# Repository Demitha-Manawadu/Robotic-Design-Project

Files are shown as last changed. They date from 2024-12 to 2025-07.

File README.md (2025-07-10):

# Robotic Design Project - EN2533

## project overview 

# My Project

This is  the Demo Video of the project - [here]( https://www.linkedin.com/posts/demitha-manawadu-9750452a4_robotics-engineering-innovation-activity-7279574753667858432-JbwE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).

This project is focused on designing and building a robot capable of performing various tasks in an autonomous environment. The robot is equipped with sensors and actuators to handle tasks such as bar counting, line navigation, maze navigation, box manipulation, and more. This robot is designed for use in the EN2533 - Robot Design and Competition module and follows a modular design approach to handle different tasks sequentially.

WhatsApp Image 2024-12-21 at 21 46 30_15445ea4               
WhatsApp Image 2024-12-21 at 21 46 29_c666b268

## Features

- 🚗 **Line Navigation:** Navigate predefined paths using IR sensor arrays and color sensors.
- 🔢 **Bar Counting:** Detect and count horizontal bars placed along a predefined path.
- 🧭 **Maze Navigation:** Grab a virtual box and navigate through a maze to place it in the target location.
- 🤖 **Box Arrangement:** Arrange a set of boxes in ascending or descending order of height using a custom SolidWorks-designed mechanical robot arm powered by servo motors. A Sharp IR sensor integrated into the robotic gripper allows for height differentiation.
- 🌈 **Color Line Following:** Follow a colored line on the ground using color sensors.
- 📏 **Dashed Line Following:** Follow a dashed line using the IR sensors.
- 🚪 **Portal Navigation:** Detect and navigate through portals or gateways.
- 🕵️‍♂️ **Hidden Task and Chamber Insertion:** Solve a hidden task and insert a box inside a chamber.
- 🪙 **Coin Drop:** Drop a coin into a specific target area.

## Design Overview

### Hardware requirements:
Sensors

The robot employs various sensors for accurate detection and navigation, including:

- **Ultrasonic Sensors:** Employed for detecting walls and chambers.
- **Sharp IR Sensor:** Mounted on top for measuring distance, especially during portal navigation and for box height differentiation.
- **TCS34725 Color Sensor:** Used for color detection in line following tasks.
- **REKHA TCRT5000 Reflectance Sensor Array:** For precise line tracking.

 **Actuators**
- Robotic arm and gripper: Gripper mechanism and slider operations for lifting boxes are performed using two MG90S servo motors.

**JGA25-370 DC motor**
- integrated to the wheels of the robot.

 **Microcontrollers**
- Arduino Mega 2560- The microcontroller that controls all the functionalities of the robot

### Mechanical Design

The mechanical design of the robot was fully customized using SolidWorks, encompassing both the chassis and the robotic arm. The robotic arm, equipped with a gripper, utilizes a rack-and-pinion mechanism for precise linear movement, enabling efficient box grabbing, lifting, and dropping operations.

The chassis features a two-layer acrylic board structure, mounted with spacers for stability. This compact design was carefully crafted to optimize space and ensure the robot can effectively carry out its tasks.
WhatsApp Image 2024-12-29 at 15 23 47_e17c57a6

WhatsApp Image 2024-12-29 at 15 19 25_0207914a

WhatsApp Image 2024-12-29 at 15 19 25_487d0368

## Algorithms

The robot’s navigation algorithms rely on real-time data from the sensors. Each task follows a defined sequence, enabling the robot to adapt its actions based on sensor inputs. The algorithms include:

## Task-2024
The full Task Documentation can be found in:
[Task 2024 v1.1](https://online.uom.lk/mod/resource/view.php?id=432368)



### task 01
### Counting and Line Navigation
The robot will travel along a straight path at a steady pace, guided by encoder feedback. As it encounters a barcode, it will measure the duration that the central IR sensor is exposed to white segments. This duration will be compared to a predetermined threshold, and if it exceeds the threshold, the value 1 will be recorded; otherwise, 0 will be stored. The robot will continue this detection process until three consecutive 0s are detected, indicating the end of the barcode.



### task 02
### Virtual Box Movement
If the Output is 0: The robot approaches the virtual box, grabs it, and moves forward to place it at a specific location. 

The robot identifies which of the two squares (blue or red) is free from gate, grabs the box, and navigates through the maze, ensuring it places the box at the appropriate location.

Movements are carefully controlled accoriding to the given constraints. The optimal path will be hardcoded and the encoders and sensor array with PD will be used for correct navigation.



### task 03
### Color line following
We use the TCS34725 color sensor alongside the REKHA TCRT5000 reflectance sensor array for accurate tracking. 

First, we calibrate the REKHA array to differentiate between the line and the background. The TCS34725 is calibrated to detect the hue of the colored line and this value will be stored for the future use in task 6.

The REKHA array keeps the robot centered on the path, while the TCS34725 verifies it's following the correct color.



### task 04
### Dotted Line Navigation
The robot follows a white dashed line using an 8-IR sensor array, dynamically adjusting its speed based on sensor input.

It maintains a forward stare when detecting black, and upon detecting the white line, it follows the path accordingly.

The robot stops when all sensors detect the white line simultaneously, signaling the end of the dashed line segment



### task 05
### Portal Navigation
For portal navigation, the ToF sensor is mounted on top of the robot (which we are going to use for height mesuring), continuously reading the distance to the gate. 

As the gate is opening and the distance starts to decrease, the robot uses this data to determine when to move forward. 
The frequent readings from the ToF sensor allow the system to  passes through the gate without collision. 
And for more accuracy we will use the ultrasonic sensor reading which is mounted in front of the robot as an additional data whether there is no obstacle in front of it.



### task 06
### Box Arrangement
When robot moves near to boxes it measures the height of each box using sharp IR sensor which is attached to the up down mechanism of the robot arm. It can differenciate the heights of 5,10,15 boxes.

Then accoring to the paths we define robot will grab the each box and place them according to the ascending or descending order depending on the colour it detected.



### task 07
### Hidden Task and Chamber Insertion
The line following robot will navigate along a the path and grab the box at stage 7 using the gripper, an ultra sonic sensor will detect the chamber and the robot will stop precisely right infront of it, release the box, will close the gripper and push the box inside the chamber using the closed gripper.



### task 08
### Coin Drop and Task Completion
The robot will move in the uneven terrain and detect walls using an ultra sonic sensor and move while avoiding the walls, until a black cross is detected to the IR sensor array.

once a cross is detected the robot will and the coin will be released on the cross using a sliding mechanism thats inbuilt in to the chassis of the robot



## Task Allocation
Provide an overview of the tasks allocated to different team members.

- **Team Member 1**: [Eshan S.G.S 220148G]
  - Tasks: [Task 2,Coding for Line following ,Implement the alogorithm for maze solving,Task 8,Testing robot behavior,coding for task 3,and 4]

- **Team Member 2**: [Manawadu M.D-220381M]
  - Tasks: [task 6,task 7,Desinging the robot arm and chasis,implement the alogorithm for box arrangement,mounting the robot mechanism]

- **Team Member 3**: [Wickramasinghe S.D-220701X]
  - Tasks: [task 1,Power circuit designing and soldering,Assembling the robot ,Testing the robot behavior, coin drop mechanism designing and implementing]
  - 
- **Team Member 4**: [Gunasekara V.G.V-220193M]
  - Tasks: [Solidworks drawing for robot arm and chisis,Coding for task 6 and 7,assembling the robot arm]
 
- **Team Member 5**: [Ravishan B.B.N-220533H]
   - Tasks: [task 5,circuit designing and robot assembling,Testing the robot behavior]

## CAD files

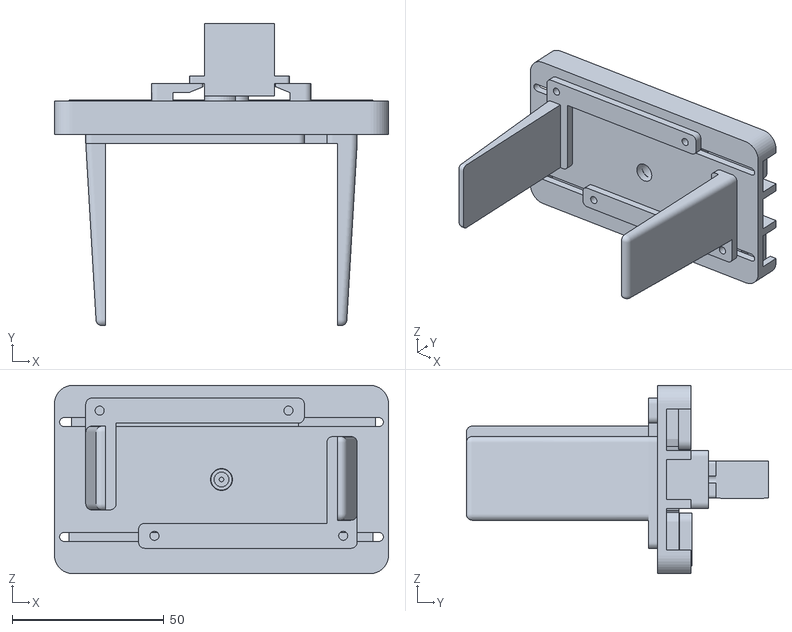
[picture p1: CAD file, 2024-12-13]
solidworks files/gripper/assembly of gripper.STL
110.0 x 99.6 x 62.0

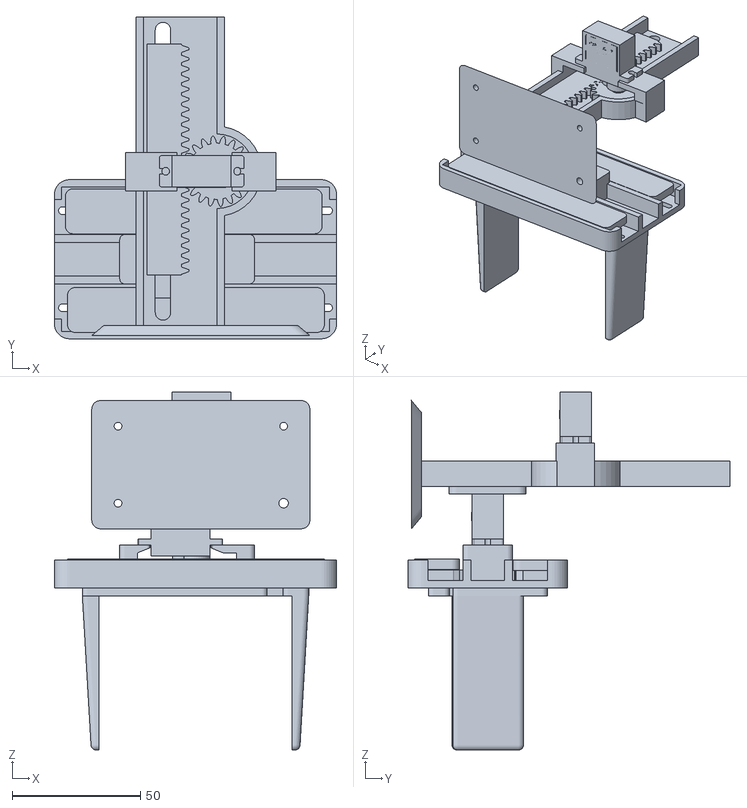
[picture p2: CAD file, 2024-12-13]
solidworks files/assembly/arm assem.STL
110.0 x 125.3 x 139.4

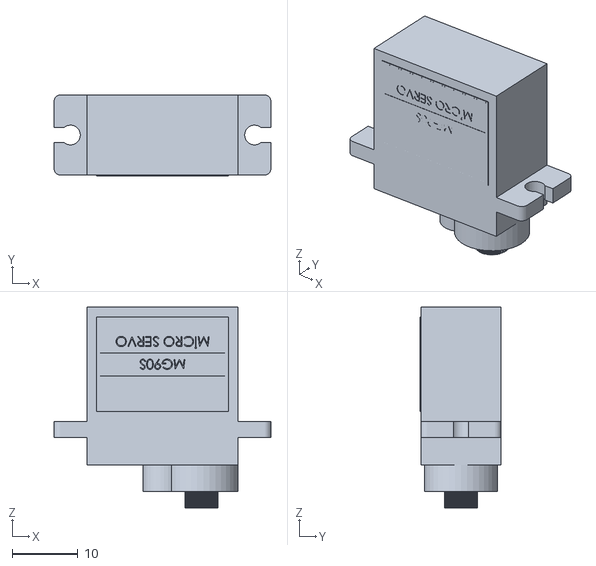
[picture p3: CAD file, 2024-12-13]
solidworks files/casing/arm assem - MG90-servo-1.STL
33.0 x 12.3 x 30.5

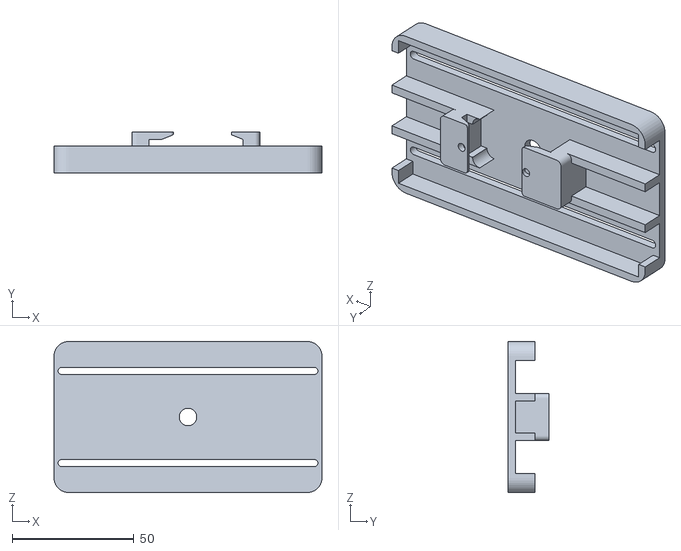
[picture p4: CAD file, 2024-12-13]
solidworks files/gripper/gripper assem - casing-1.STL
110.0 x 16.8 x 62.0

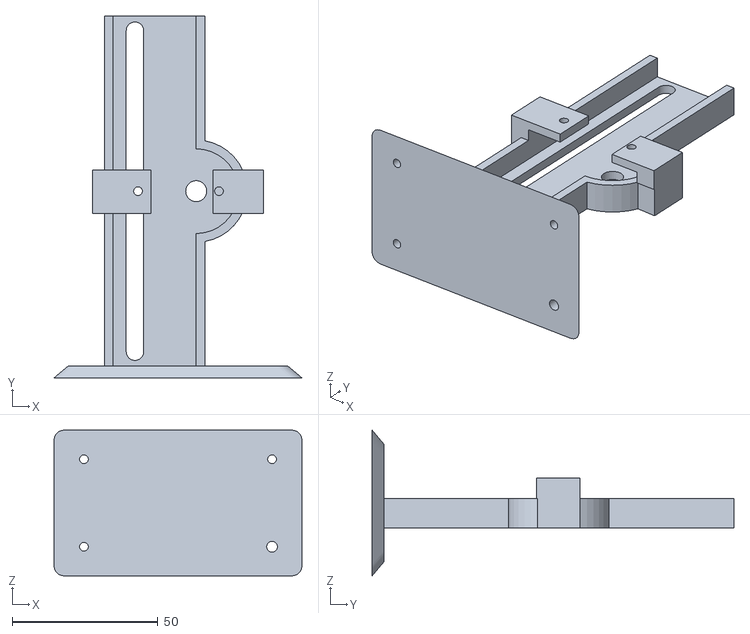
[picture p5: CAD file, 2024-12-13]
solidworks files/casing/arm assem - casing_new_arm-1.STL
85.0 x 124.0 x 50.0

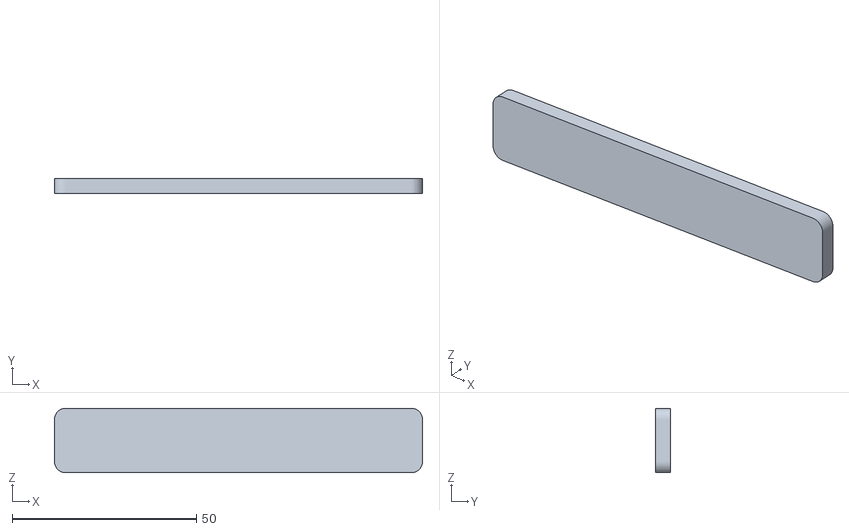
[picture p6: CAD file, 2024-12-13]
solidworks files/gripper/gripper assem - plate_gripper-1.STL
100.0 x 4.00 x 17.5

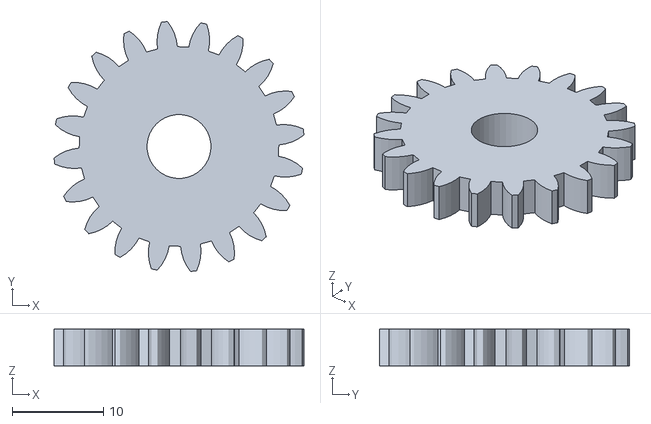
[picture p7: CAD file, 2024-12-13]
solidworks files/casing/arm assem - spur gear_am-1.STL
27.4 x 27.4 x 4.00

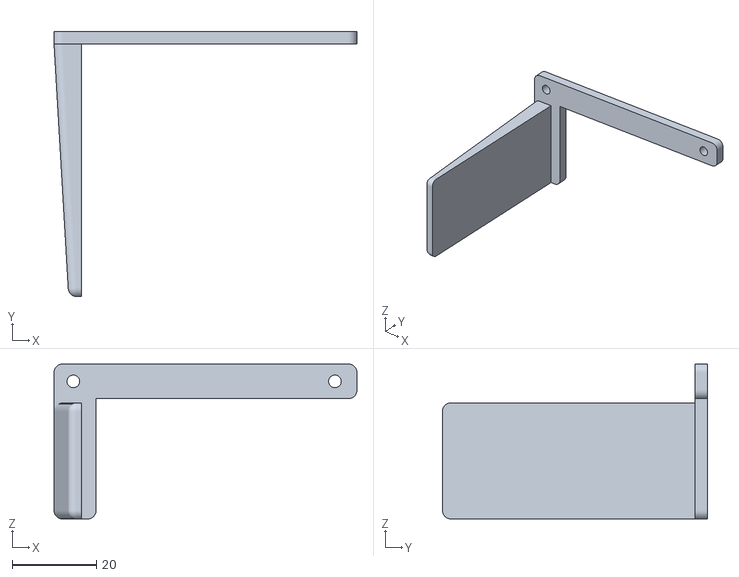
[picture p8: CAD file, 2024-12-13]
solidworks files/gripper/gripper assem - gripper jaw-1.STL
72.0 x 63.0 x 36.8

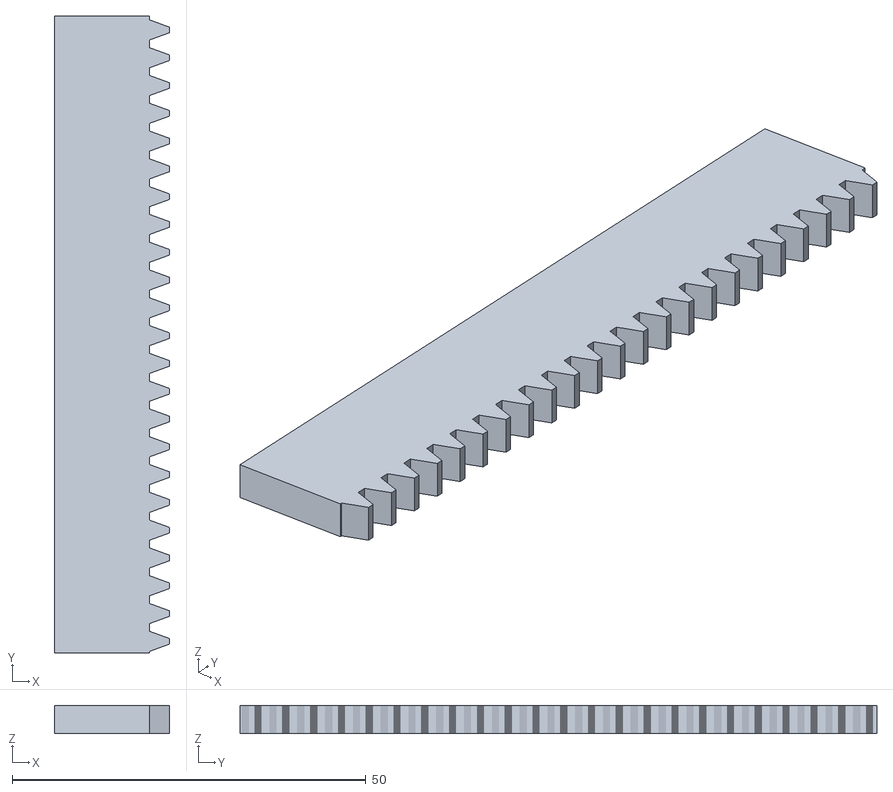
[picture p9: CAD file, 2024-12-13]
solidworks files/casing/arm assem - rack spur rectangular_am-1.STL
16.2 x 90.0 x 4.00

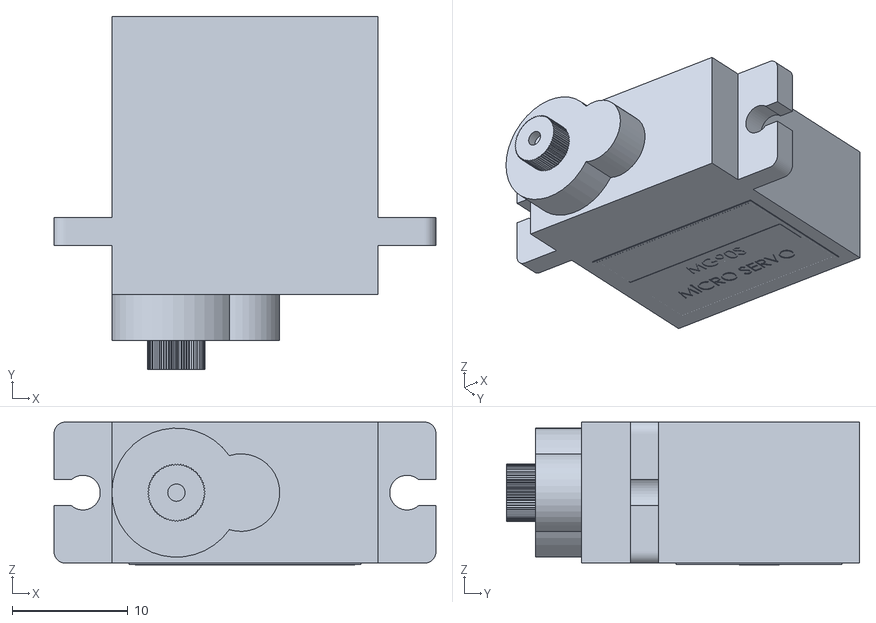
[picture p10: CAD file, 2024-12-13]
solidworks files/gripper/gripper assem - MG90-servo-1.STL
33.0 x 30.5 x 12.4

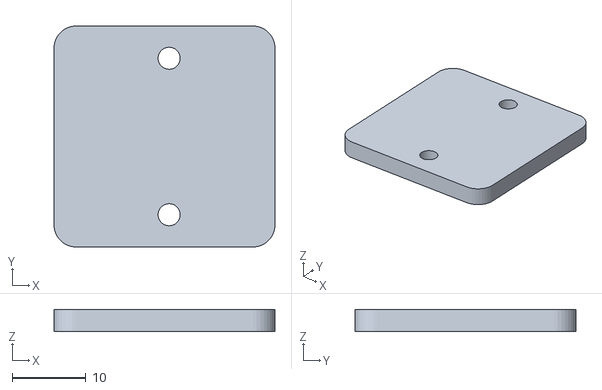
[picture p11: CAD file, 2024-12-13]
solidworks files/casing/arm assem - square-1.STL
30.0 x 30.0 x 3.00

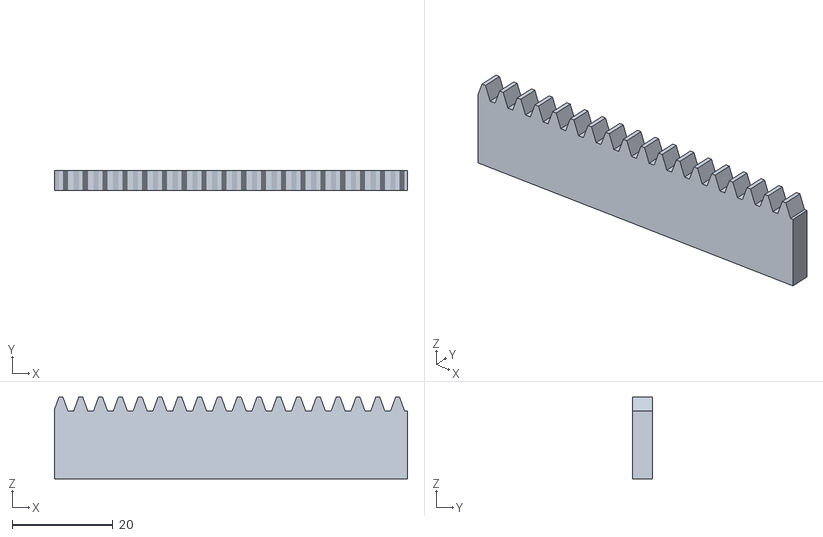
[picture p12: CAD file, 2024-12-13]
solidworks files/gripper/gripper assem - rack spur rectangular_am-4.STL
70.0 x 4.00 x 16.2

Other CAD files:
solidworks files/gripper/gripper assem - gripper jaw-2.STL
solidworks files/gripper/gripper assem - rack spur rectangular_am-7.STL
solidworks files/gripper/gripper assem - plate_gripper-2.STL
solidworks files/gripper/gripper assem - spur gear_am-2.STL

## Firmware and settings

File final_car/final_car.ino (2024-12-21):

#include <Arduino.h>
#include "PIDControl.h"
#include "SensorControl.h"
#include "MotorControl.h"
#include "Buzzer.h"
#include "ColorSensor.h"
#include "LineFollowAndTurn.h"
#include "task2.h"
#include "button.h"
#include "menu.h"
#include "OLED_Display.h"
#include "roboArm.h"
ButtonReader myBtnReader;
Buzzer buzzer;
//ColorSensor colorSensor;
OLEDDisplay oled; // single OLED object
#include "coindrop.h"
#include "Barcode.h"
void setup() {
  void setuplikesetup();
  setupsen() ;
  setupServo();
  Serial.begin(9600);
  myBtnReader.initPins();
  oled.init(); 
  initializeSensors();
  //calibrateSensors();
  setupEncoders();
  setupMotors();
  menu_init();
  digitalWrite(53,LOW);
  digitalWrite(51,LOW);
  digitalWrite(49,LOW);
  // put your setup code here, to run once:

}

void loop() {
    button_t btn = myBtnReader.readButton();
  if (btn != BTN_NONE) {
    menu_update(btn); // update menu logic
  }
  menu_draw(); // draw current menu state
  delay(10);
  // put your main code here, to run repeatedly:

}

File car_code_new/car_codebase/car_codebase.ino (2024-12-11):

#include "MotorControl.h"
#include "SensorControl.h"
#include "AdvancedMotorControl.h"
#include "MovementControl.h"
#include "OLED_Display.h"
#include "BarcodeDetection.h"
#include "Buzzer.h"
#include "ColorSensor.h"
#include "LineFollowAndTurn.h"
#include "task2.h"
#include "button.h"
#include "menu.h"

ButtonReader myBtnReader;
Buzzer buzzer;
ColorSensor colorSensor;
OLEDDisplay oled; // single OLED object

const int threshold = 500;
const int maxLines = 3;    
const int targetSpeed = 180;
BarcodeDetection barcodeDetector(threshold, maxLines, targetSpeed);

void setup() {
  Serial.begin(9600);
  myBtnReader.initPins();
  oled.init();  // initialize OLED
  setupMotors();
  buzzer.playBeep(); 
  setupSensors();
  buzzer.playBeep();    
  setupEncoders();

  menu_init(); // initialize menu
}

void loop() {
  button_t btn = myBtnReader.readButton();
  if (btn != BTN_NONE) {
    menu_update(btn); // update menu logic
  }
  menu_draw(); // draw current menu state
  delay(10);
}

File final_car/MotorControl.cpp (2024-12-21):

#include "MotorControl.h"
#include <Arduino.h>
#include "OLED_Display.h"
#include "PIDControl.h"

const int leftMotorForward = 48;
const int leftMotorBackward = 50;
const int rightMotorForward = 46;
const int rightMotorBackward = 44;

const int enaPin = 8;
const int enbPin = 9;

// Encoder pins
const int leftEncoderB = 18;
const int leftEncoderA = 19;
const int rightEncoderB = 3;
const int rightEncoderA = 2;

// Encoder counts
volatile long leftEncoderCount = 0;
volatile long rightEncoderCount = 0;

// // Constants to map degrees to encoder counts
// const float ENCODER_COUNTS_PER_DEGREE = 11.99;  // Adjust this value based on your setup

// PID control variables for turning
float turnKp = 1.0;  // Proportional gain for turning
float turnKi = 0.0;  // Integral gain for turning
float turnKd = 0.5;  // Derivative gain for turning
float turnLastError = 0;
float turnIntegral = 0;

void setupMotors() {
  pinMode(leftMotorForward, OUTPUT);
  pinMode(leftMotorBackward, OUTPUT);
  pinMode(rightMotorForward, OUTPUT);
  pinMode(rightMotorBackward, OUTPUT);
  pinMode(enaPin, OUTPUT);
  pinMode(enbPin, OUTPUT);
}

void setupEncoders() {
  pinMode(leftEncoderA, INPUT);
  pinMode(leftEncoderB, INPUT);
  pinMode(rightEncoderA, INPUT);
  pinMode(rightEncoderB, INPUT);

  // Attach interrupts to encoder pins
  attachInterrupt(digitalPinToInterrupt(leftEncoderA), leftEncoderISR, CHANGE);
  attachInterrupt(digitalPinToInterrupt(rightEncoderA), rightEncoderISR, CHANGE);
}

void leftEncoderISR() {
  if (digitalRead(leftEncoderA) == digitalRead(leftEncoderB)) {
    leftEncoderCount++;
  } else {
    leftEncoderCount--;
  }
}

void rightEncoderISR() {
  if (digitalRead(rightEncoderA) == digitalRead(rightEncoderB)) {
    rightEncoderCount++;
  } else {
    rightEncoderCount--;
  }
}
void resetEncoders(){
  rightEncoderCount=0;
  leftEncoderCount=0;
} 
// Stop all motors
void stopMotors() {
  analogWrite(enbPin, 0);
  analogWrite(enaPin, 0);
  digitalWrite(leftMotorForward, HIGH);
  digitalWrite(leftMotorBackward, HIGH);
  digitalWrite(rightMotorForward, HIGH);
  digitalWrite(rightMotorBackward, HIGH);
  delay(10);
}


void moveForward(int leftSpeed, int rightSpeed) {
  analogWrite(enbPin, leftSpeed);  // Set speed for left motor
  analogWrite(enaPin, rightSpeed); // Set speed for right motor
  digitalWrite(leftMotorForward, HIGH);
  digitalWrite(leftMotorBackward, LOW);
  digitalWrite(rightMotorForward, HIGH);
  digitalWrite(rightMotorBackward, LOW);
}

// Move backward with specific speeds for left and right motors
void moveBackward(int leftSpeed, int rightSpeed) {
  analogWrite(enbPin, leftSpeed);  // Set speed for left motor
  analogWrite(enaPin, rightSpeed); // Set speed for right motor
  digitalWrite(leftMotorForward, LOW);
  digitalWrite(leftMotorBackward, HIGH);
  digitalWrite(rightMotorForward, LOW);
  digitalWrite(rightMotorBackward, HIGH);
}
void turnByAngleWithPID(int angle) {
  // Convert the angle into target encoder counts
  long encoderTarget = abs(angle) * 11.75;
  leftEncoderCount = 0;
  rightEncoderCount = 0;

  // PID control loop
  while (abs(leftEncoderCount) < encoderTarget && abs(rightEncoderCount) < encoderTarget) {
    long error = abs(leftEncoderCount) - abs(rightEncoderCount);

    // PID calculation
    turnIntegral += error;
    float derivative = error - turnLastError;
    float output = turnKp * error + turnKi * turnIntegral + turnKd * derivative;
    turnLastError = error;

    // Adjust motor speeds based on PID output
    int baseSpeed = 180;  // You can adjust this base speed as needed
    int leftSpeed = baseSpeed + output;
    int rightSpeed = baseSpeed - output;

    // Ensure motor speeds are within valid range
    leftSpeed = constrain(leftSpeed, 150, 250);
    rightSpeed = constrain(rightSpeed, 150, 250);

    if (angle > 0) {
      // Turn right: left motor moves forward, right motor moves backward
      analogWrite(enbPin, leftSpeed);
      analogWrite(enaPin, rightSpeed);
      digitalWrite(leftMotorForward, HIGH);
      digitalWrite(leftMotorBackward, LOW);
      digitalWrite(rightMotorForward, LOW);
      digitalWrite(rightMotorBackward, HIGH);
    } else {
      // Turn left: left motor moves backward, right motor moves forward
      analogWrite(enbPin, leftSpeed);
      analogWrite(enaPin, rightSpeed);
      digitalWrite(leftMotorForward, LOW);
      digitalWrite(leftMotorBackward, HIGH);
      digitalWrite(rightMotorForward, HIGH);
      digitalWrite(rightMotorBackward, LOW);
    }
  }

  // Stop motors after reaching the target
  stopMotors();
}

void corrector() {
  unsigned long startTime = millis();
  while (millis() - startTime < 500) {  // Run for approximately 1 second
    runForwardWithSensorPID();
  }
}
void runForwardWithoutPID(long targetCount) {
    leftEncoderCount = 0;
    rightEncoderCount = 0;

    // Keep moving forward until the encoder counts reach the target
    while (abs(leftEncoderCount) < targetCount && abs(rightEncoderCount) < targetCount) {
        moveForward(120, 120);  // Move both motors at a fixed speed
    }
    // Stop the motors after reaching the target count
    stopMotors();
}
void runBackwardWithoutPID(long targetCount) {
    leftEncoderCount = 0;
    rightEncoderCount = 0;

    // Keep moving forward until the encoder counts reach the target
    while (abs(leftEncoderCount) < targetCount && abs(rightEncoderCount) < targetCount) {
        moveBackward(150, 150);  // Move both motors at a fixed speed
    }
    // Stop the motors after reaching the target count
    stopMotors();
}
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

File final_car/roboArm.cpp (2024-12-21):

#include <Servo.h>
#include <Arduino.h>
#include "SensorControl.h"
#include "PIDControl.h"
#include "task2.h"
#include "MotorControl.h"
#include "roboArm.h"
int length=1550;
// Create servo objects for two servos
Servo myServo;       // Servo for grabbing/dropping the box
Servo liftServo;     // Servo for lifting/lowering the gripper

const int sensorPin = A15; // Analog pin connected to Sharp IR sensor output
int boxHeight;
int boxHeight2;
int boxHeight3;
// Function to read the analog value from the Sharp IR sensor
int readSharpAnalog() {
  return analogRead(sensorPin); // Return the analog reading
}

// Function to move a servo smoothly to a target angle
void smoothMove(Servo &servo, int startAngle, int endAngle, int delayTime) {
  if (startAngle < endAngle) {
    for (int pos = startAngle; pos <= endAngle; pos++) {
      servo.write(pos);
      delay(delayTime); // Smooth transition
    }
  } else {
    for (int pos = startAngle; pos >= endAngle; pos--) {
      servo.write(pos);
      delay(delayTime); // Smooth transition 
    }
  }
}

// Function to grab the box (servo on pin 6)
void grabBox() {
  smoothMove(myServo, 180, 0, 15); // Smoothly move from 180 to 0 degrees
  delay(500); // Hold the box for 2 seconds
}

// Function to drop the box (move gradually and release)
void dropBox() {
  smoothMove(myServo, 0, 180, 15);  // Smoothly move to 90 degrees
  delay(500); 
  runBackwardWithoutPID(300);                    // Pause for the box to start releasing                  // Wait for 2 seconds
}

// Function to lift the gripper (servo on pin 9)
void liftGripper() {
  smoothMove(liftServo, 0, 180, 15); // Move from 90° (down) to 0° (up)
  delay(500);                      // Hold the position for 1 second
}

// Function to lower the gripper (servo on pin 9)
void lowerGripper() {
  smoothMove(liftServo, 180, 0, 15); // Move from 0° (up) to 90° (down)
  delay(500);                      // Hold the position for 1 second
}

// Function to determine the height of the box
int detectBoxHeight() {
  // Move to 7 cm position (7cm position is mapped to the 0 degrees position/ starting position)
  liftServo.write(0);

  // Take sensor reading at the starting point
  int sensorValue = readSharpAnalog();
  bool detectedAt7cm = sensorValue > 100; // Threshold for detection (adjust as needed)
  delay(500);
  if (!detectedAt7cm) {
    return 5; // Box height is 5 cm
  }

  // Move to 13 cm position (is mapped to the 180 degrees position)
  smoothMove(liftServo, 0, 180, 15);
  delay(500);

  sensorValue = readSharpAnalog();
  bool detectedAt13cm = sensorValue > 100; // Threshold for detection
  delay(500);
  if (detectedAt7cm && !detectedAt13cm) {
    return 10; // Box height is 10 cm
  }
  if (detectedAt7cm && detectedAt13cm) {
    return 15; // Box height is 15 cm
  }

  return -1; // Error case (should not reach here)
}

void setupServo() {
  Serial.begin(9600); // Initialize Serial communication

  // Attach the servos to their respective pins
  myServo.attach(11);      // Gripper servo on pin 6
  liftServo.attach(12);    // Lifting servo on pin 9

  // Initialize both servos to their starting positions
  myServo.write(180);      // Gripper open position
  liftServo.write(0);   // Gripper down position
  delay(1000);            // Wait for servos to initialize
}

void task6() {

  bluee=1-gate;
  whiteline=false;
  if (bluee){
    goForwardAndHandleJunction('L');
    runForwardWithoutPID_1(length);
    int boxHeight = detectBoxHeight();
    Serial.print("Box Height: ");
    Serial.println(boxHeight);
    lowerGripper();
    delay(500);
    grabBox();        // Close the gripper to grab the box
    delay(500); 
    liftGripper(); //move the gripper up
    delay(500);
    turnByAngleWithPID(-180);
      if (boxHeight==5){
        goForwardAndHandleJunction('S');
        runForwardWithoutPID_1(length);
        lowerGripper();   // Move the gripper down
          delay(500);      // Wait 1 second
          dropBox();        // Open the gripper to release the box
          delay(500);

          turnByAngleWithPID(-180);
          goForwardAndHandleJunction('R');
          goForwardAndHandleJunction('L');
          runForwardWithoutPID_1(length);
      }
      else if (boxHeight==10){
          goForwardAndHandleJunction('L');
          goForwardAndHandleJunction('R');
          runForwardWithoutPID_1(length);
          lowerGripper();   // Move the gripper down
          delay(500);      // Wait 1 second
          dropBox();        // Open the gripper to release the box
          delay(500);

          turnByAngleWithPID(-180);
          goForwardAndHandleJunction('S');
          runForwardWithoutPID_1(length);
      }
      else {
          goForwardAndHandleJunction('L');
          goForwardAndHandleJunction('S');
          goForwardAndHandleJunction('R');
          runForwardWithoutPID_1(length);
          lowerGripper();   // Move the gripper down
          delay(500);      // Wait 1 second
          dropBox();        // Open the gripper to release the box
          delay(500);

          turnByAngleWithPID(-180);
          goForwardAndHandleJunction('L');
          goForwardAndHandleJunction('R');
          runForwardWithoutPID_1(length);
      }
    int boxHeight2 = detectBoxHeight();
    Serial.print("Box Height: ");
    Serial.println(boxHeight2);
    lowerGripper();
    delay(500);
    grabBox();        // Close the gripper to grab the box
    delay(500); 
    liftGripper(); //move the gripper up
    delay(1000);
    turnByAngleWithPID(-180);
      if (boxHeight2==10){
        goForwardAndHandleJunction('S');
        runForwardWithoutPID_1(length);
        lowerGripper();   // Move the gripper down
          delay(500);      // Wait 1 second
          dropBox();        // Open the gripper to release the box
          delay(500);

          turnByAngleWithPID(-180);
          goForwardAndHandleJunction('R');
          goForwardAndHandleJunction('L');
          runForwardWithoutPID_1(length);
      }
      else if (boxHeight2==5){
          goForwardAndHandleJunction('R');
          goForwardAndHandleJunction('L');
          runForwardWithoutPID_1(length);
          lowerGripper();   // Move the gripper down
          delay(500);      // Wait 1 second
          dropBox();        // Open the gripper to release the box
          delay(500);

          turnByAngleWithPID(-180);
          goForwardAndHandleJunction('R');
          goForwardAndHandleJunction('S');
          goForwardAndHandleJunction('L');
          runForwardWithoutPID_1(length);
      }
      else {
          goForwardAndHandleJunction('L');
          goForwardAndHandleJunction('R');
          runForwardWithoutPID_1(length);
          lowerGripper();   // Move the gripper down
          delay(500);      // Wait 1 second
          dropBox();        // Open the gripper to release the box
          delay(500);
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

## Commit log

2024-12-08 Added STL files for arm and gripper
    [arm assem - MG90-servo-1.STL, arm assem - casing_new_arm-1.STL, arm assem - rack spur rectangular_am-1.STL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]
2024-12-08 added the assembly of gripper as one stl file
    [assembly of gripper.STL]
2024-12-30 Create power circuit
